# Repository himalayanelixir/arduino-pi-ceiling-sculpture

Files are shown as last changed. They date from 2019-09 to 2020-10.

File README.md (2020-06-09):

# Arduino Pi Ceiling Sculpture
<!-- vscode-markdown-toc -->
* [Summary](#Summary)
* [Setup](#Setup)
	* [Arduino](#Arduino)
	* [Raspberry Pi](#RaspberryPi)
* [Use](#Use)
	* [Format of the messages](#Formatofthemessages)
	* [Using the CVSs](#UsingtheCVSs)

<!-- vscode-markdown-toc-config
	numbering=false
	autoSave=true
	/vscode-markdown-toc-config -->
<!-- /vscode-markdown-toc -->

## Summary

Runs a ceiling sculpture using a Raspberry Pi as a master and multiple Arduinos as slaves. Thanks to the way the code is written, it's trivial to adapt code for any project that uses a text ui and cvs to send commands to as many Arduinos as you want!

Because the code is heavily commented, the focus of this README will be to get the code installed and then how to use the text ui to send commands to the Arduinos.

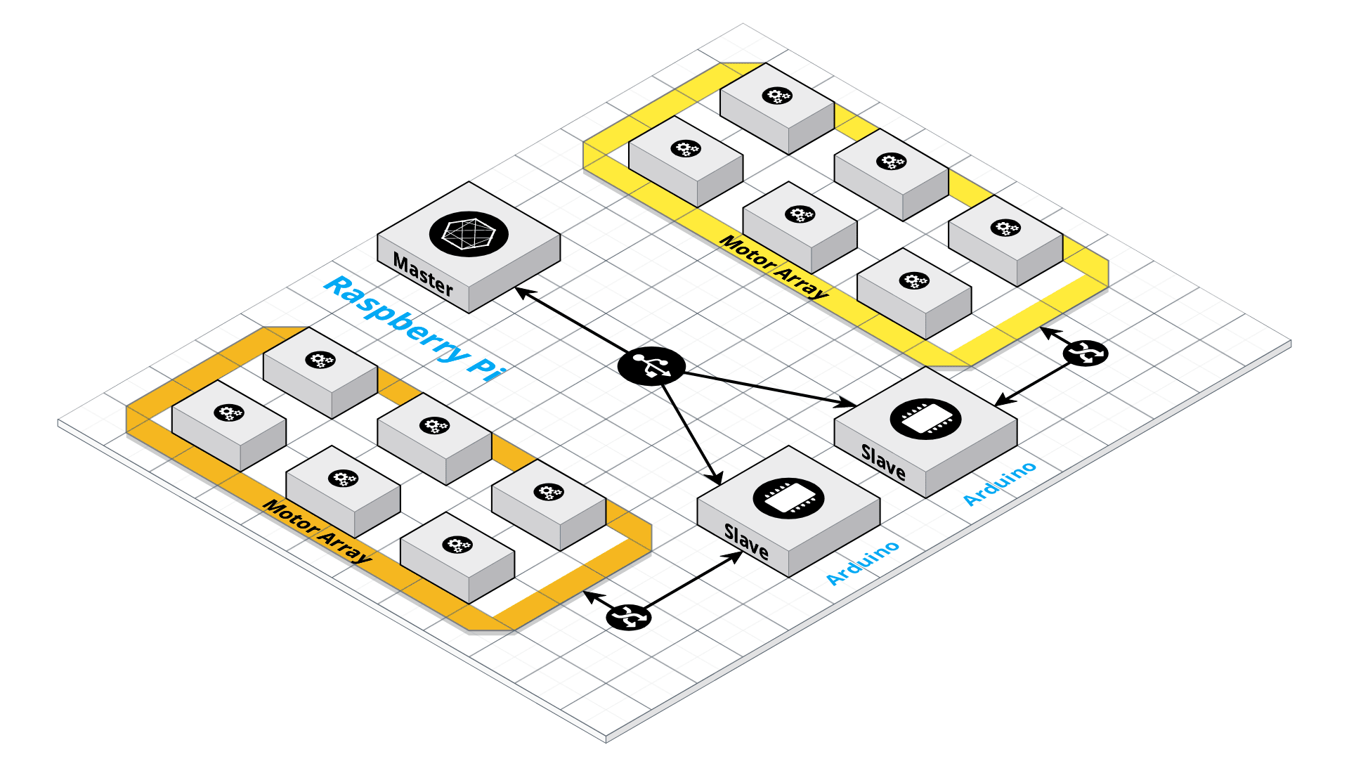
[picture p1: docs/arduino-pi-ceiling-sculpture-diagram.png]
Diagram

<p align="center"><i>Entire system</i></p>

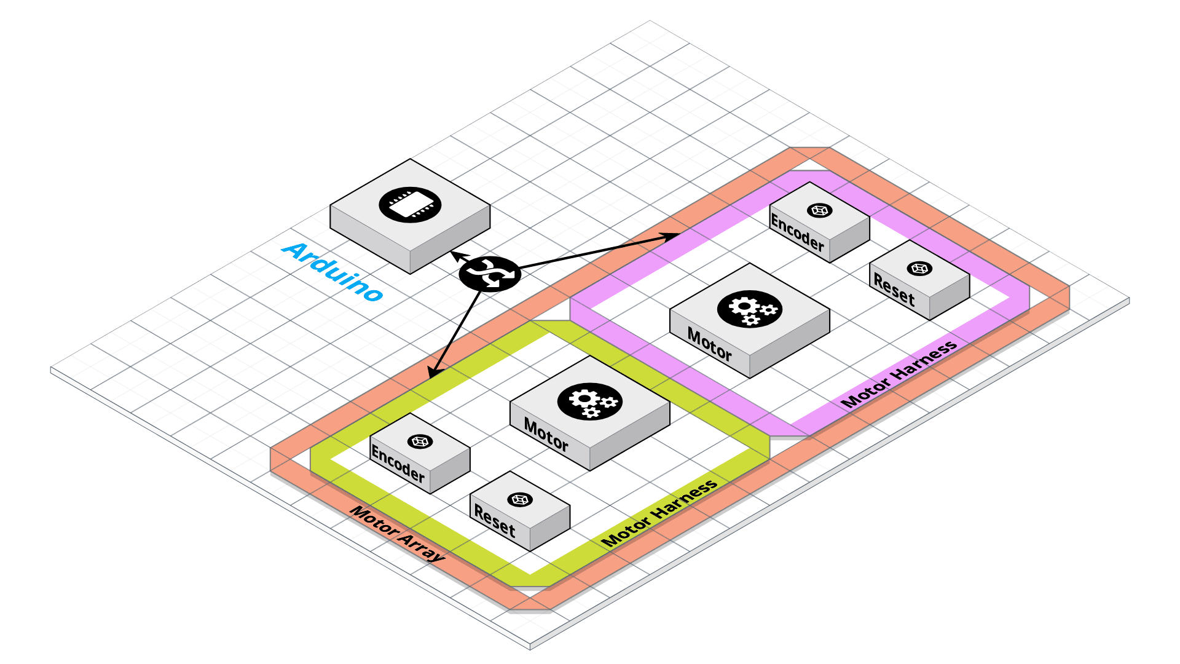
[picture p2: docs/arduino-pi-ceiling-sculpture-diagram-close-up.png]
Diagram

<p align="center"><i>Close up of an motor array</i></p>

## Setup

### Arduino

In the repo you will find the Arduino code under ```arduino/arduino.ino```. Open this in the Arduino IDE or CLI and flash to the devices you are using.

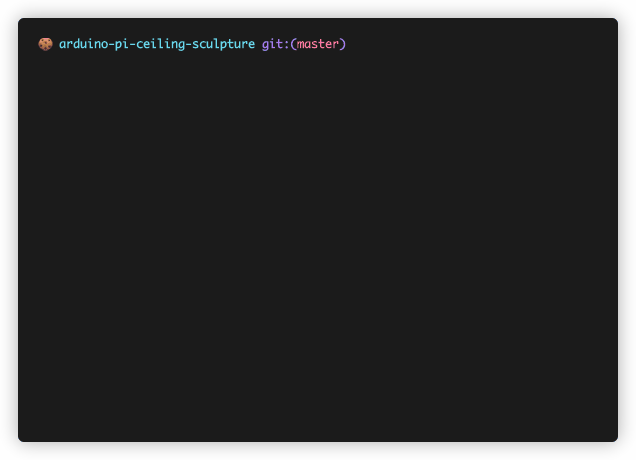
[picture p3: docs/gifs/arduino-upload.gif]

<p align="center"><i>Steps using the Arduino CLI</i></p>

There are only a few variables that can to be modified. Note that in this project and array refers to the combination of an Arduino and the motors that are connected to it. Each motor consists of a servo motor, and encoder switch, and a reset switch.

| Variable | Default | Description |
|---|---|---|
| DEBOUNCE_TIME | 0.4 | modifies the debounce time of the switches in the encoder. It is an arbitrary number and changed depending on the switches used for the encoder and reset |
| ARRAY_NUMBER | 0 | every array in the installation must have a unique array number that is between 0 and MAX_ARRAY_NUMBER (set on the Raspberry Pi) |
| NUMBER_OF_MOTORS | 1 | number of motors that you want to connect to this array |
| NUMBER_OF_MOTORS_MOVING | 1 | the execution of the commands is staggered/ cascaded from motor number 0 to NUMBER_OF_MOTORS. This is done to limit the amount of power being drawn at any one time|
| TIMEOUT | 50000 | this number counts the number of loops before the array returns a timeout error to the raspberry pi. The mount of time a loop takes is arbitrary and this number should be adjusted depending on what you need|
| IGNORE_INPUT_TIME | 150 | once the reset is hit we ignore inputs from the encoder switch for a certain number of loops. This is done so we skip an edge when moving down one turn from a reset event |
ports | {array}| array that contains the mapping of port number, function, and motor number

### Raspberry Pi

The Raspberry Pi setup is mostly automated using the script found at ```raspberry-pi/image-setup/firstboot.sh```. In the current setup I have an Raspberry connected to an Adafruit PiTFT Plus screen (<https://www.adafruit.com/product/2298>). If you aren't using the screen you can comment out those parts of the ```firstboot.sh``` script.  Also you can comment out the parts where it sets up the ```/raspberry-pi/gui.py``` file for the screen.

Note: The ```firstboot.sh``` pulls files from Github when running. The default is to pull from ```https://raw.githubusercontent.com/himalayanelixir/arduino-pi-ceiling-sculpture/master/``` change this if you want to pull from your own repo.

The best way to get everything working properly is to follow these steps:
1. Download the latest image from <https://github.com/nmcclain/raspberian-firstboot/releases>
2. Use etcher to write to the SD card (<https://www.balena.io/etcher/>)
3. Copy over ```raspberry-pi/image-setup/firstboot.sh``` and ```raspberry-pi/image-setup/wpa_supplicant.conf``` to boot partition of SD card. Remember to edit the `wpa_supplicant.conf` file with the details for your wifi network
4. Put the SD card into Raspberry Pi and boot. This will take a while but shouldn't take more than 30 mins. If it does, something probably went wrong.

It is important to note that ```firstboot.sh``` configures UFW (Uncomplicated Firewall) to block all outgoing and incoming network connections other than port 22 (SSH) from 192.168.1.0/24 (local network). This is done since we don't want the Raspberry Pi being accessed outside the local network or to pull updates which might break the applications. To connect to disable UFW run ```sudo ufw disable``` and enable using ```sudo ufw enable```.

There are a few variables that can be changed.

| Variable | Default | Description |
|---|---|---|
| MAX_TURNS | 10 | maximum number of turns a motor can take from 0 position used when linting csv files |
| MAX_NUMBER_OF_ARRAYS | 4 | maximum number of arrays allowed. Used then linting csv files |
| MAX_NUMBER_OF_MOTORS | 10 | maximum number of motors allowed. Used when linting csv file |
| USB_PATH | "/dev/ttyU*" | path the code looks for Arduinos at. All USB devices found will be considered to be Arduinos. |
| DESIRED_STATE_FILENAME | "desired-state.csv" | CSV file we are using to store our desired state for the ceiling |
| CURRENT_STATE_FILENAME | "current-state.csv" | CSV file we are using to store the current state of the ceiling |

## Use

Once the Arduinos are flashed and the Raspberry Pi is setup you plug the Arduinos into the Raspberry Pi. When you SSH into the Raspberry Pi using the pi user ```controller.pi``` will automatically run.

### Format of the messages

The messages between the Raspberry Pi and the Arduinos are formatted in strings. For example the string  ```<Up,1,Down,1>``` will tell the Arduino to move motor 0 up one turn and move motor 1 down 1 turn. You can even try this using the serial monitor in the Arduino IDE.

### Using the CVSs

```controller.py``` uses two CSVs to figure out what messages to send to the Arduinos. ```desired-state.csv``` contains a CVS which is used by the user to specify how many turns from 0 they want each motor to be at.

```current-state.csv``` contains the data on where each motor is currently. Both files are linted for size and contents before they are diffed and instructions are created. Any values that are out of the range of ```MAX_NUMBER_OF_MOTORS``` and ```MAX_NUMBER_OF_ARRAYS``` will be dropped. Any values that are blank, not integers, or don't exist will be filled with zeros. Values that are to large and too small will be replaced with ```MAX_TURNS``` or zero accordingly.

<p align="center"><img src="https://raw.githubusercontent.com/himalayanelixir/arduino-pi-ceiling-sculpture/master/docs/gifs/pi-controller.gif"></p>
<p align="center"><i>Running controller.py</i></p>

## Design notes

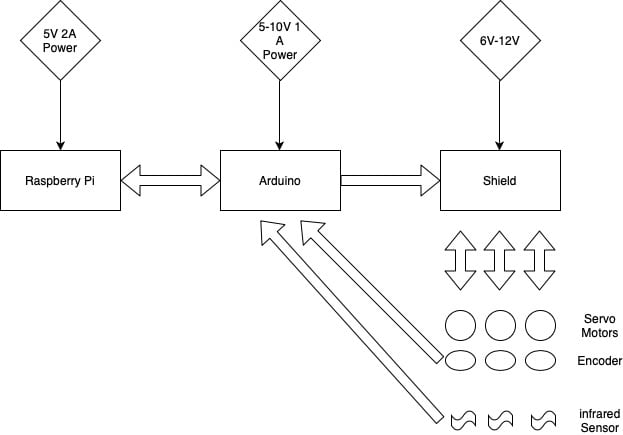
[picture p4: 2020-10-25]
parts/motor-harness/initial-design.jpg

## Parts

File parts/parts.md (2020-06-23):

<!-- vscode-markdown-toc -->
* [Parts](#Parts)

<!-- vscode-markdown-toc-config
	numbering=false
	autoSave=true
	/vscode-markdown-toc-config -->
<!-- /vscode-markdown-toc -->

## Parts

| Part | Part Name |
|---|---|
| Motors | FS5109R-V2 6V 10kg digital 360° Continuous Rotation Servo (FS5109R-C005) |
| 2 Pin Connectors  | KF301-2P |
| 3 Pin Connectors  | KF301-3P |
| 4 Pin Connectors  | KF301-4P |
| Male Headers | Male Header 0.1" 2.54mm Breadboard PCB Strip Connectors |
| Female Headers | Female Header 0.1" 2.54mm PCB Strip Connectors |
| Voltage Regulator | Pololu 9V Step-Up Voltage Regulator U3V12F9 |
| Arduino | Arduino Mega 2560 R3 |
| Raspberry Pi | Raspberry Pi 3 B+ |
| Power Wire | KabelDirekt - Pure Copper Stereo Audio Speaker - 16 AWG Gauge - 50 Feet  |
| Signal Wire | EWCS 22 AWG 3/C Str CMR Riser Rated Non-Shielded Sound & Security Cable  |
| PCBs | Oshpark |
| Switches | Cherry Red PCB Mount |
| Filament | SUNLU Wood Filament 2kg - 1.75 mm |
| Filament | Essentium PCTG |
| USB Cable | SNANSHI 25 Foot USB 2.0 Type A Male to Type B Male |
| Power Connectors  | WAGO 221-413 Lever-Nuts 3 Conductor Compact Connectors |
| Twine | Berkley Trilene Big Game Monofilament Custom Spool (30lbs) |
| Nozzle (Mounts) | Micro Swiss Plated Wear Resistant Nozzle .5mm |
| Nozzle (Tubes) | Micro Swiss Plated Wear Resistant Nozzle .8mm for Robo 3D |
| Hotend | RepRapDiscount Hexagon AO Hotend 1.75mm Kit |

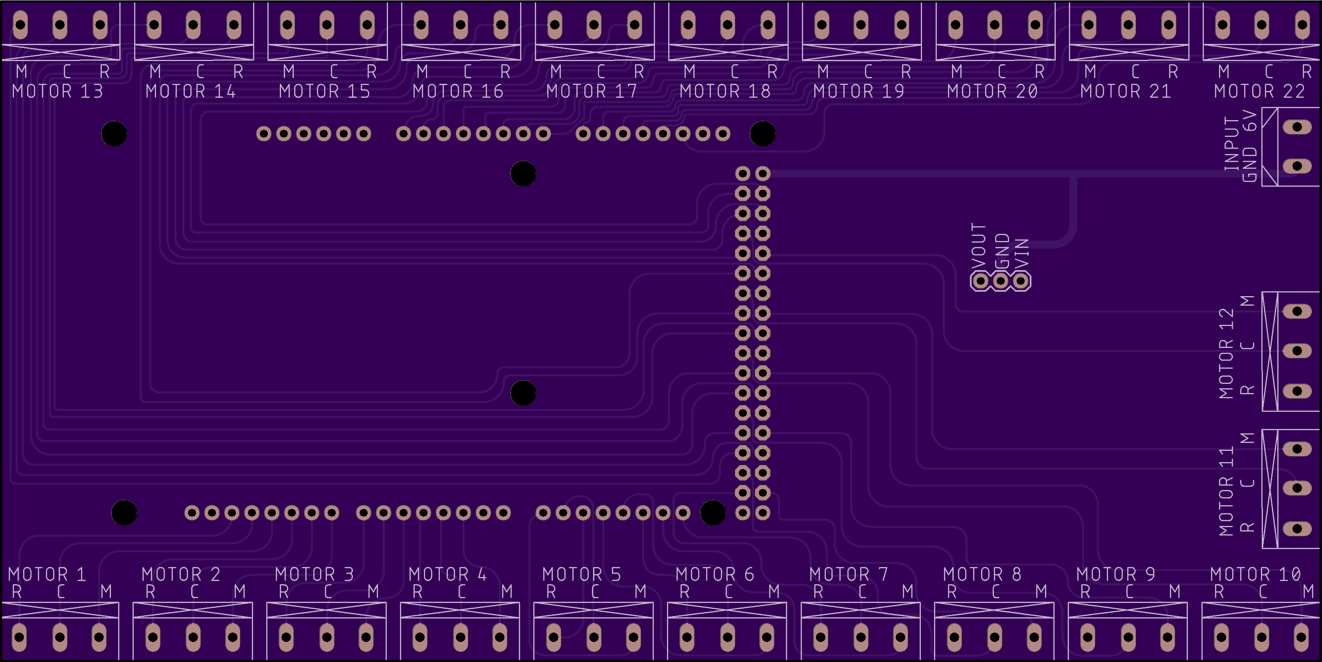
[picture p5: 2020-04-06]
parts/pcbs/arduino-top.png

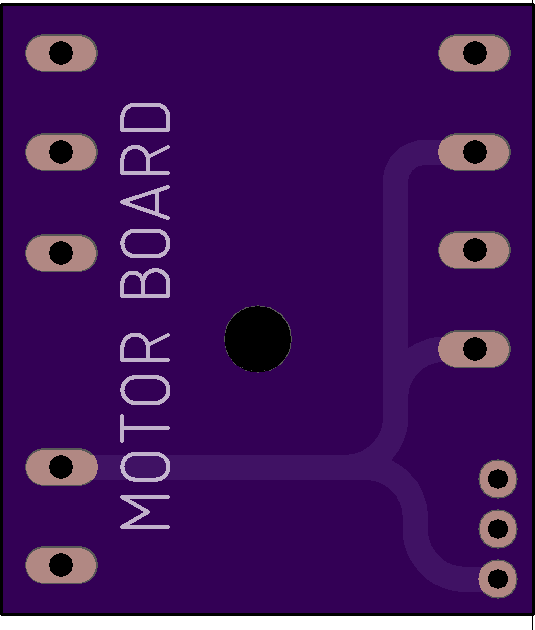
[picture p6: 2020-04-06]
parts/pcbs/motor-bottom.png

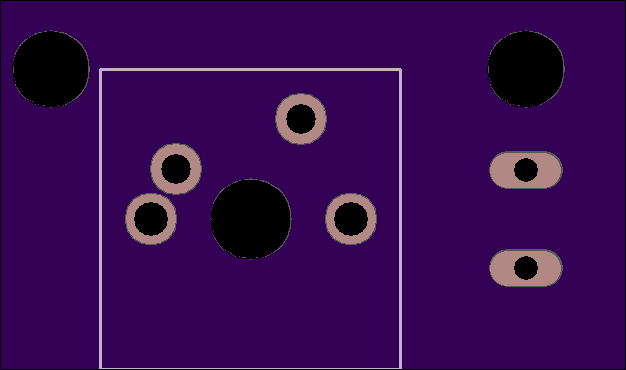
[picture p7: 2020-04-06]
parts/pcbs/switch-bottom.png

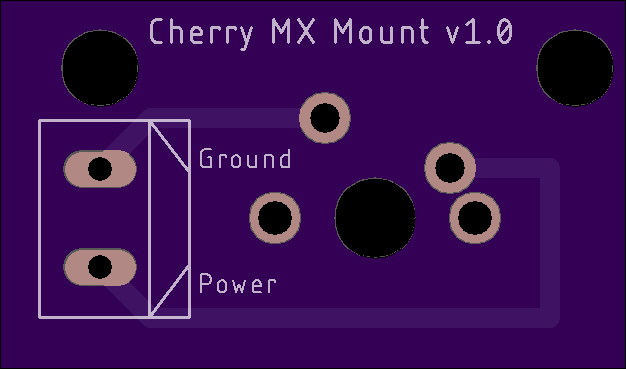
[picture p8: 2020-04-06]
parts/pcbs/switch-top.png

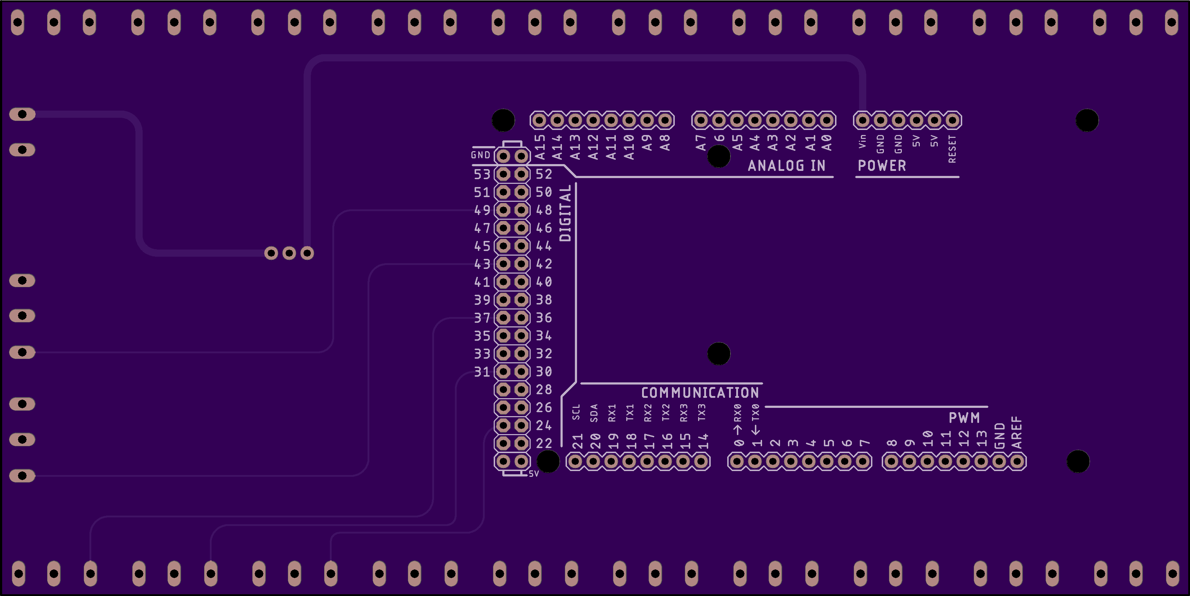
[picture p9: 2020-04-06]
parts/pcbs/arduino-bottom.png

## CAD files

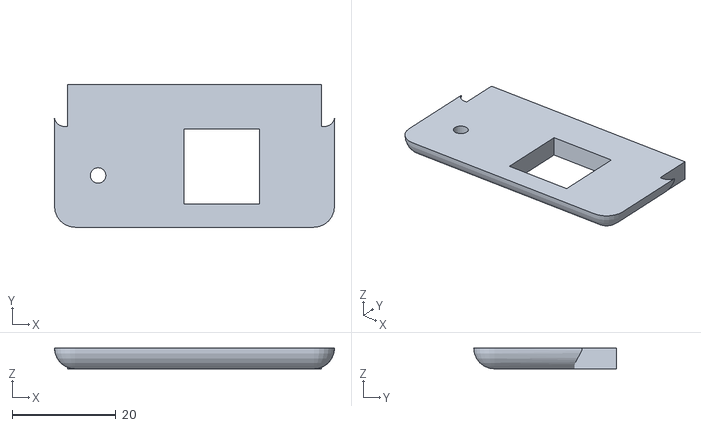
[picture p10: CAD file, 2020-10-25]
parts/motor-harness/mount5_part2.stl
54.0 x 27.5 x 4.00

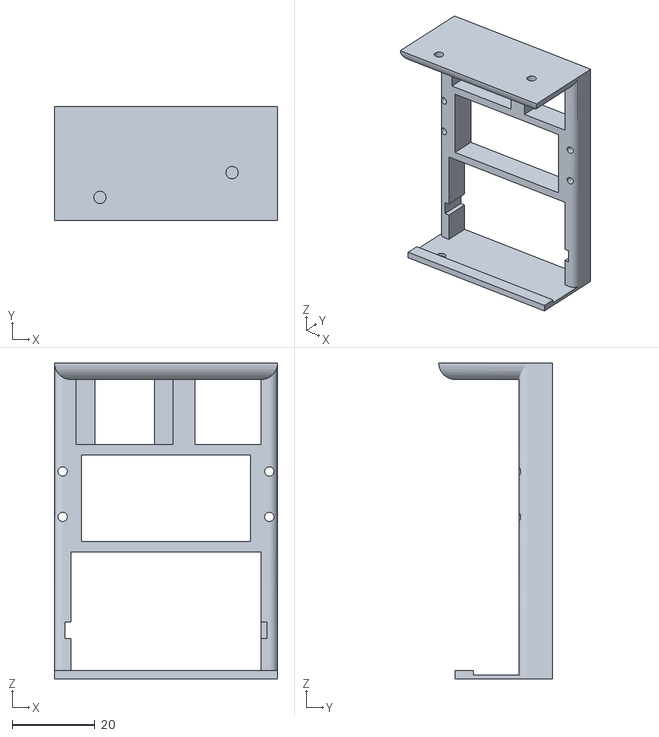
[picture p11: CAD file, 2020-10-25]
parts/motor-harness/mount5_part1.stl
54.0 x 27.5 x 76.5

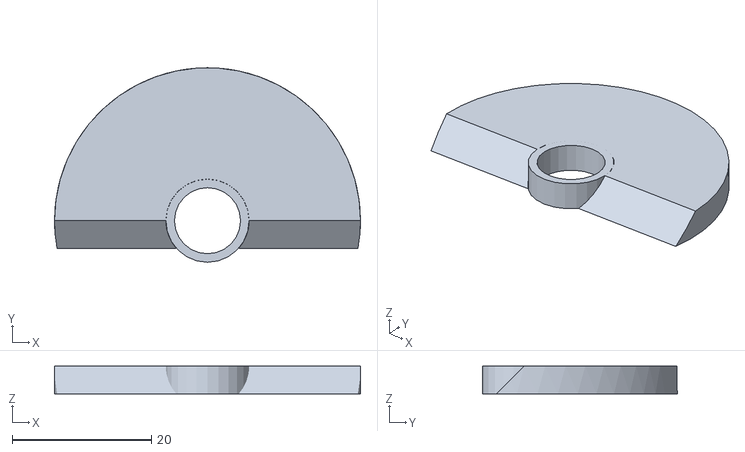
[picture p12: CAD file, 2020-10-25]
parts/motor-harness/spool5_part1.stl
44.0 x 28.0 x 4.00

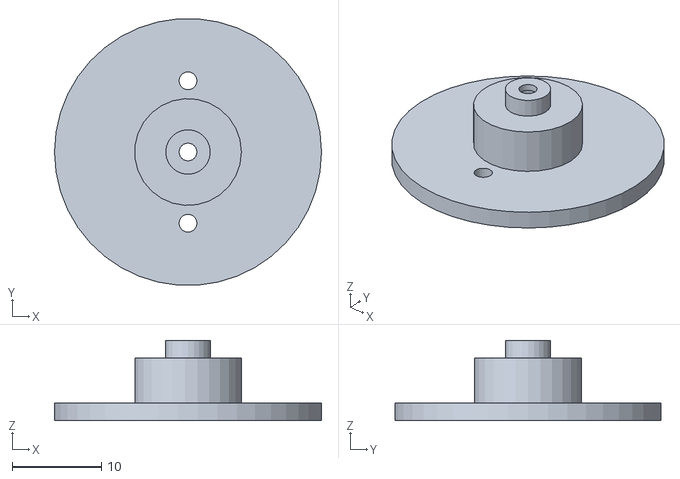
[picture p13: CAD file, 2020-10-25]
parts/motor-harness/spool5_part2.stl
30.0 x 29.9 x 9.00

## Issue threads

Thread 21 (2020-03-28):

Update README.md

himalayanelixir, 2020-03-28:
Provide instructions on how to get started with the code for both Arduino and Raspberry Pi

himalayanelixir, 2020-04-04:
1. Brief Overview
2. Setup Arduino
3. Setup Raspberry Pi
4. Functionality
pi -> arduino
input -> execution (error) -> result

Closed 2020-04-06.

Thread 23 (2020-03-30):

refactor controller.py to reduce complexity and make maintenance easier

himalayanelixir, 2020-03-30:
- currently the code is too nested and complex
- remove global variables if possible
- get pylint errors reduced
- add comments to the file

Closed 2020-03-31.

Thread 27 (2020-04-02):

fix pylint error

himalayanelixir, 2020-04-02:
raspberry-pi/controller.py:452:0: R0912: Too many branches (17/12) (too-many-branches)

Closed 2020-04-02.

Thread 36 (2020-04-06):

refactor broke arduino code - fix

himalayanelixir, 2020-04-06:
arduino doesn't accept commands anymore.

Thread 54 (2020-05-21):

motor timeout error not returning motor numbers

himalayanelixir, 2020-05-21:

himalayanelixir, 2020-05-21:
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

Closed 2020-05-23.

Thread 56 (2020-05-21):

motor out of range error isn't being caught

himalayanelixir, 2020-05-21:
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

himalayanelixir, 2020-05-21:
also display array number

himalayanelixir, 2020-05-21:
needs reformatting so error is raised only after all linting is complete on the array and motor numbers

Closed 2020-05-22.

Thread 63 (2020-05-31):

ufw setup bug

himalayanelixir, 2020-05-31:
ufw rules and enable aren't happening during firstboot all of a sudden - troubleshoot

himalayanelixir, 2020-05-31:
`# block all internet access other than incoming ssh from local network
# outgoing isn't blocked by default, we don't want updates unless we explicitly disable the firewall
ufw default deny outgoing
# allow local ssh
ufw allow from 192.168.0.0/16 to any port 22
# allow mDNS discovery on local network so 'ping raspberrypi.local' works
ufw allow out 5353/udp
# enable ufw, will auto start on boot
sudo ufw -f enable`

Closed 2020-06-04.

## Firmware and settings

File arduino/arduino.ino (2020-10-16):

// Copyright 2020 Harlen Bains
// Linted using cpplint
// Google C++ Style Guide https://google.github.io/styleguide/cppguide.html
#include <Servo.h>
#include <String.h>
// constants
// #define MAXIMUM_DEBOUNCE 8
#define MAXIMUM_DEBOUNCE 40
#define MAXIMUM_NUMBER_OF_MOTORS 22
#define ARRAY_NUMBER 0
#define NUMBER_OF_MOTORS 1
#define NUMBER_OF_MOTORS_MOVING 5
#define TIMEOUT 50000
#define MESSAGE_CHAR_LENGTH 300
// variables for communication
char received_chars[MESSAGE_CHAR_LENGTH];
bool new_data = false;
// create servo objects
Servo my_servo[NUMBER_OF_MOTORS];
// create a array of ports with the order: motor, counter, reset
int ports[MAXIMUM_NUMBER_OF_MOTORS][3] = {
    {11, 12, 13}, {8, 9, 10}, {5, 6, 7}, {2, 3, 4}, {14, 15, 16}, {17, 18, 19},
    {20, 21, 22}, {23, 24, 25}, {29, 30, 31}, {35, 36, 37}, {41, 42, 43},
    {47, 48, 49}, {26, 27, 28}, {32, 33, 34}, {38, 39, 40}, {44, 45, 46},
    {50, 51, 52}, {53, 54, 55}, {56, 57, 58}, {59, 60, 61}, {63, 64, 65},
    {62, 66, 67}
};
// integer array that contains the direction and number of rotations a motor,
// and a flag that determines if it's moving
int motor_commands[NUMBER_OF_MOTORS][3] = { 0 };
// array of new switch values
byte motor_sensor_counter1[NUMBER_OF_MOTORS] = { 0 };
// array of old switch values
byte motor_sensor_counter2[NUMBER_OF_MOTORS] = { 0 };
// Previous return value (CheckSwitch function)
int previous_value[NUMBER_OF_MOTORS] = { 1 };
// 0 or 1 depending on the input signal
byte input[NUMBER_OF_MOTORS] = { 0 };
// will range from 0 to the specified MAXIMUM_DEBOUNCE
int integrator[NUMBER_OF_MOTORS] = { 0 };
// cleaned-up version of the input signal
byte output[NUMBER_OF_MOTORS] = { 0 };
// other variables needed for the ProcessData() function
bool go = true;
int total_turns = 0;
int timeout_counter = 0;
int moving_motors = 0;
bool did_timeout = false;

void RecvWithStartEndMarkers() {
  // handles the receiving of data over the serial port
  static bool receive_in_progress = false;
  static int char_count = 0;
  char start_marker = '<';
  char end_marker = '>';
  char receive_from_usb;
  while (Serial.available() > 0 && new_data == false) {
    receive_from_usb = Serial.read();
    if (receive_in_progress == true) {
      if (receive_from_usb != end_marker) {
        received_chars[char_count] = receive_from_usb;
        char_count++;
        if (char_count >= MESSAGE_CHAR_LENGTH) {
          char_count = MESSAGE_CHAR_LENGTH - 1;
        }
      } else {
        received_chars[char_count] = '\0';  // terminate the string
        receive_in_progress = false;
        char_count = 0;
        new_data = true;
      }
    } else if (receive_from_usb == start_marker) {
      receive_in_progress = true;
    }
  }
}

void Finished() {
  // sends message back to raspberry pi saying the command has been executed
  if (did_timeout == true) {
    Serial.print("\033[31mRECIEVED: TIMEOUT - MOTOR(S): ");
    for (int i = 0; i < NUMBER_OF_MOTORS; i++) {
      if (motor_commands[i][1] != 0) {
        Serial.print(i);
        Serial.print(" ");
      }
    }
    Serial.print("\033[0m>");
  } else {
    Serial.print("\033[32mRECIEVED: SUCCESS\033[0m>");
  }
  for (int i = 0; i < NUMBER_OF_MOTORS; i++) {
    my_servo[i].write(90);
    motor_commands[i][0] = 0;
    motor_commands[i][1] = 0;
    motor_commands[i][2] = 0;
  }
}

void PopulateArray() {
  // fills array with instructions from the raspberry pi
  // temp string used to store the char array
  // easier to do opperations on string than chars
  String received_string = "";
  // give the string the value of the char array
  received_string = received_chars;
  // now lets populate the motor command array with values from the received
  // string
  for (int i = 0; i < NUMBER_OF_MOTORS; i++) {
    // we break everything in to pairs of values
    int search_1 = (i *2);
    int search_2 = ((i *2) + 1);

    String value_1 = GetValue(received_string, ',', search_1);
    String value_2 = GetValue(received_string, ',', search_2);

    if (value_1 == "Up") {
      motor_commands[i][0] = 1;
      // need to add one to up commands to deal with integrator and counter
      // values, forcing an edge
      motor_commands[i][1] = value_2.toInt() + 1;
      integrator[i] = 0;
      motor_sensor_counter1[i] = 0;
      motor_sensor_counter2[i] = 0;
    } else if (value_1 == "Down") {
      motor_commands[i][0] = 2;
      motor_commands[i][1] = value_2.toInt() + 1;;
      integrator[i] = MAXIMUM_DEBOUNCE;
      motor_sensor_counter1[i] = 1;
      motor_sensor_counter2[i] = 1;
    } else {
      motor_commands[i][0] = 0;
      motor_commands[i][1] = 0;
    }
  }
}

String GetValue(String data, char separator, int index) {
  // helps get a particular value from the incoming data string
  int found = 0;
  int string_index[] = { 0, -1 };
  int maximum_index = data.length() - 1;

  for (int i = 0; i <= maximum_index && found <= index; i++) {
    if (data.charAt(i) == separator || i == maximum_index) {
      found++;
      string_index[0] = string_index[1] + 1;
      string_index[1] = (i == maximum_index) ? i + 1 : i;
    }
  }
  return found > index ? data.substring(string_index[0], string_index[1]) : "";
}

void ProcessData() {
  // function that moves the motors and executes till they are done moving or
  // timeout
  while (go == true) {
    // initialize motors and get them moving
    for (int i = 0; i < NUMBER_OF_MOTORS; i++) {
      CountMoving();
      if (moving_motors < NUMBER_OF_MOTORS_MOVING &&
        motor_commands[i][2] != 1) {
        if (motor_commands[i][1] != 0) {
          StartMotors(i);
          motor_commands[i][2] = 1;
        }
      }
    }

    // subtract from motor rotations when a rotation is detected
    for (int i = 0; i < NUMBER_OF_MOTORS; i++) {
      if (motor_commands[i][2] == 1) {
        CheckCounter(i);
        // stop motors that have reached 0
        if (motor_commands[i][1] <= 0) {
          my_servo[i].write(90);
          motor_commands[i][2] = 0;
        }
      }

      // stop motors that have hit the reset
      // first stop the motor and then tell the code to move it down one
      // rotation
      if (digitalRead(ports[i][2]) == 0) {
        my_servo[i].write(110);
        motor_commands[i][0] = 2;
        motor_commands[i][1] = 1;
        motor_commands[i][2] = 0;
      }
    }
    // see how many turns are left in the array
    // we want to zero it every time we recalculate the number of turns
    total_turns = 0;
    for (int i = 0; i < NUMBER_OF_MOTORS; i++) {
      total_turns += motor_commands[i][1];
    }
    // exit loop if there are no more motor rotations remaining
    if (total_turns <= 0) {
      go = false;
    }
    timeout_counter = timeout_counter + 1;
    // time out loop if stall
    if (timeout_counter >= TIMEOUT) {
      go = false;
      did_timeout = true;
      for (int i = 0; i < NUMBER_OF_MOTORS; i++) {
        my_servo[i].write(90);
      }
    }
  }
}

int CountMoving() {
  // count the number of moving motors
  moving_motors = 0;
  for (int i = 0; i < NUMBER_OF_MOTORS; i++) {
    moving_motors += motor_commands[i][2];
  }
}

void CheckCounter(int i) {
  // check to see if we are on a rising edge
  motor_sensor_counter2[i] = motor_sensor_counter1[i];
  motor_sensor_counter1[i] = CheckSwitch(i, ports[i][1]);
  if (motor_commands[i][0] == 1) {
    // if up
    if (motor_sensor_counter1[i] == 1 && motor_sensor_counter2[i] == 0) {
      motor_commands[i][1] = motor_commands[i][1] - 1;
    }
  } else {
    // if down
    if (motor_sensor_counter1[i] == 0 && motor_sensor_counter2[i] == 1) {
      motor_commands[i][1] = motor_commands[i][1] - 1;
    }
  }
  if (motor_commands[i][1] < 0) {
    motor_commands[i][1] = 0;
  }
}

int CheckSwitch(int motor_number, int switchPort) {
  // check to see if the encoder switch is pressed or not
  /*Step 1: Update the integrator based on the input signal.  Note that the
  integrator follows the input, decreasing or increasing towards the limits
  as determined by the input state (0 or 1). */
  input[motor_number] = digitalRead(switchPort);

  if (input[motor_number] == 0) {
    if (integrator[motor_number] > 0)
      integrator[motor_number]--;
  } else {
    if (integrator[motor_number] < MAXIMUM_DEBOUNCE)
      integrator[motor_number]++;
  }
  /*Step 2: Update the output state based on the integrator.  Note that the
  output will only change states if the integrator has reached a limit,
  either 0 or MAXIMUM_DEBOUNCE. */
  if (integrator[motor_number] <= 0) {
    previous_value[motor_number] = 0;
    return (0);
  } else if (integrator[motor_number] >= MAXIMUM_DEBOUNCE) {
    previous_value[motor_number] = 1;
    return (1);
  } else {
    return (previous_value[motor_number]);
  }
}

void StartMotors(int i) {
  // move motors
  if (motor_commands[i][0] == 1) {
    // Move up
    my_servo[i].write(80);
  } else if (motor_commands[i][0] == 2) {
    // Move down
    my_servo[i].write(110);
  } else {
    // Don't Move
    my_servo[i].write(90);
  }
}

void setup() {
  // setup serial port
  Serial.begin(9600);
  for (int i = 0; i < NUMBER_OF_MOTORS; i++) {
    // initialize all motor ports
    int x = ports[i][0];
    my_servo[i].attach(x);
    // initialize all counter ports
    int y = ports[i][1];
    pinMode(y, INPUT_PULLUP);
    // initialize all reset ports
    int z = ports[i][2];
    pinMode(z, INPUT_PULLUP);
    // zero all motors and initialize reset variables
    my_servo[i].write(90);
    motor_sensor_counter1[i] = 1;
    motor_sensor_counter2[i] = 1;
    output[i] = 1;
  }
  Serial.print("<Arduino is Ready Array Number: ");
  Serial.print(ARRAY_NUMBER);
  Serial.print(" Number of Motors: ");
  Serial.print(NUMBER_OF_MOTORS);
  Serial.print(">");
}

void loop() {
  // check to see if there is any new data
  RecvWithStartEndMarkers();
  // if there is new data process it
  if (new_data == true) {
    new_data = false;
    go = true;
    did_timeout = false;
    timeout_counter = 0;
    Serial.print("<");
    PopulateArray();
    ProcessData();
    Finished();
  }
}

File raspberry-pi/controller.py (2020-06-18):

#!/home/pi/code/pi_env/bin/python3
# Copyright 2020 Harlen Bains
# linted using pylint
# formatted using black
# pylint: disable=duplicate-code
"""This script runs on the Raspberry Pi and sends commands to Arduinos.
Once a command is sent it then waits a reply and then loops.
"""

import csv
import shutil
import subprocess
import time
import glob
import os
from threading import Thread
import serial  # pylint: disable=import-error
from yaspin import yaspin  # pylint: disable=import-error
from yaspin.spinners import Spinners  # pylint: disable=import-error
import timeout_decorator  # pylint: disable=import-error
import questionary  # pylint: disable=import-error


# constants
# don't change
BAUD_RATE = 9600
START_MARKER = 60
END_MARKER = 62
SPINNER = yaspin(Spinners.weather)
ARDUINO_MESSAGE_TIMEOUT = 10
ARDUINO_EXECUTE_TIMEOUT = 100
# adjustable
# positive integers only
MAX_TURNS = 20
MAX_NUMBER_OF_ARRAYS = 36
MAX_NUMBER_OF_MOTORS = 22
# USB_PATH = "/dev/ttyU*"
USB_PATH = "/dev/ttyACM*"
CSV_PATH = "/home/pi/"
CURRENT_STATE_FILENAME = "code/current-state.csv"


class Error(Exception):
    """Exception that is raised when an error occurs in the program
    causes the program to print out a message and then loop.
    """


def find_arduinos():
    """Run ls command and find all USB devices connected to USB hub
     assume that all of them are Arduinos.

    Returns:
      A list of all the ports that are active on the USB hub.

    Raises:
      Error: if no arrays are found or if more than MAX_NUMBER_OF_ARRAYS is
    found.
    """
    # run ls in subprocess shell and save results
    try:
        path_command = "ls " + USB_PATH
        serial_shell_capture = subprocess.run(
            [path_command], shell=True, capture_output=True, check=True
        )
        # take results and convert byte string into utf-8 and create list based on newlines
        serial_shell_capture_list = serial_shell_capture.stdout.decode(
            "utf-8"
        ).splitlines()
        # if there is at least one array found then print out number found
        # other wise print zero and error
        print(
            f"Found \033[32m{len(serial_shell_capture_list)}\033[0m Array(s)",
            f"of Max of {MAX_NUMBER_OF_ARRAYS}",
        )
        # make sure that the # arrays found is less than or equal to MAX_NUMBER_OF_ARRAYS
        if len(serial_shell_capture_list) > MAX_NUMBER_OF_ARRAYS:
            # make list empty so we don't try to close ports when this error occurs
            serial_shell_capture_list = []
            print(
                f"\033[31mERROR: NUMBER OF ARRAYS FOUND GREATER THAN {MAX_NUMBER_OF_ARRAYS}\033[0m"
            )
            raise Error
    except subprocess.CalledProcessError:
        # need to still have a valie
        serial_shell_capture_list = []
        print(f"\nFound \033[31m0\033[0m Array(s) of Max {MAX_NUMBER_OF_ARRAYS}")
        print(f"\033[31mERROR: NO ARRAYS FOUND\033[0m")
        raise Error
    return serial_shell_capture_list


def lint_csv_file(csv_filename):
    """Lint file table is the corret size and values are valid.

    Args:
      csv_filename: The name of the file we are linting.

    Raises:
      Error: If the program can not read the file.
      Error: If the program can not write to the file.
    """
    csv_filename_list = []
    # we initialize this list to a particular size becuase we then iterate over it and
    # copy values from csv_filename_list. When copying we also make sure that the
    # values are allowed (filters out non ints and values that are too high or low)
    csv_filename_list_linted = [
        ["0" for x in range(MAX_NUMBER_OF_MOTORS)] for y in range(MAX_NUMBER_OF_ARRAYS)
    ]
    try:
        with open(csv_filename, "r") as csv_filename_file:
            csv_filename_reader = csv.reader(csv_filename_file, delimiter=",")
            csv_filename_list = list(csv_filename_reader)
            for count_row in range(0, MAX_NUMBER_OF_ARRAYS):
                for count_column in range(0, MAX_NUMBER_OF_MOTORS):
                    try:
                        # pylint: disable=C0330
                        if (
                            int(csv_filename_list[count_row][count_column]) <= MAX_TURNS
                            and int(csv_filename_list[count_row][count_column]) > 0
                            and csv_filename_list[count_row][count_column] != ""
                            and isinstance(
                                int(csv_filename_list[count_row][count_column]), int
                            )
                        ):
                            csv_filename_list_linted[count_row][
                                count_column
                            ] = csv_filename_list[count_row][count_column]
                        else:
                            csv_filename_list_linted[count_row][count_column] = "0"
                    except (IndexError, ValueError):
                        csv_filename_list_linted[count_row][count_column] = "0"
    except EnvironmentError:
        SPINNER.write(
            csv_filename + " (\033[31m" + "ERROR: CAN'T READ CSV" + "\033[0m)"
        )
        raise Error
    # write values to file overwriting previous file
    try:
        with open(csv_filename, "w", newline="") as csv_filename_file:
            csv_filename_writer = csv.writer(csv_filename_file, quoting=csv.QUOTE_ALL)
            csv_filename_writer.writerows(csv_filename_list_linted)
            SPINNER.write(csv_filename + " (\033[32m" + "COMPLETE" + "\033[0m)")
    except EnvironmentError:
        SPINNER.write(
            csv_filename + " (\033[31m" + "ERROR: CAN'T WRITE CSV" + "\033[0m)"
        )
        raise Error
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

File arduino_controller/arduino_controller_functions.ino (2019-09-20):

//////////////////////////////////////////////////////////////////////////////
//////////////////////////////////////////////////////////////////////////////

// This file contains functions that process the data that is received from the
// raspberry pi

//////////////////////////////////////////////////////////////////////////////
//////////////////////////////////////////////////////////////////////////////

void ProcessData()
{
  // Added this because reset code is different from regular movement code
  bool is_reset = false;
  bool go = true;
  int total_turns = 0;
  long timeout_counter = 0;

  PopulateArray();

  // initialize all motors and get them moving
  for (int i = 0; i < NUMBER_MOTORS; i++)
  {
    if (motor_commands[i][0] == 0)
    {
      my_servo[i].write(100);
      Serial.println("Reached Up");
      is_reset = false;
    }
    else if (motor_commands[i][0] == 1)
    {
      my_servo[i].write(80);
      Serial.println("Reached Down");
      is_reset = false;
    }
    else if (motor_commands[i][0] == 2)
    {
      my_servo[i].write(90);
      Serial.println("Reached Stopped");
      is_reset = false;
    }
    else if (motor_commands[i][0] == 3)
    {
      // Start moving pieces up
      my_servo[i].write(100);
      Serial.println("Reached Reset");
      is_reset = true;
      // call reset function (still needs to be written)
    }
    else
    {
      // Sends Error Message
    }
  }

  if (is_reset == false)
  {
    while (go == true)
    {
      // subtract from motor rotations when a rotation is detected
      for (int i = 0; i < NUMBER_MOTORS; i++)
      {
        motor_sensor_counter2[i] = motor_sensor_counter1[i];
        motor_sensor_counter1[i] = CheckSwitch(i, ports[i][1]);

        if (motor_sensor_counter1[i] == 1 && motor_sensor_counter2[i] == 0)
        {
          motor_commands[i][1] = motor_commands[i][1] - 1;
        }

        if (motor_commands[i][1] < 0)
        {
          motor_commands[i][1] = 0;
        }
      }
      // stop motors that have reached 0
      for (int i = 0; i < NUMBER_MOTORS; i++)
      {
        if (motor_commands[i][1] <= 0)
        {
          my_servo[i].write(90);
        }
      }
      // see how many turns are left in the array
      for (int i = 0; i < NUMBER_MOTORS; i++)
      {
        total_turns += motor_commands[i][1];
        // Serial.print("Total number of turns in array: ");
        // Serial.println(total_turns);
      }
      // print the total number of turns left for each motor
      for (int i = 0; i < NUMBER_MOTORS; i++)
      {
        Serial.print("Motor ");
        Serial.print(i);
        Serial.print(": ");
        Serial.print(motor_commands[i][1]);
        Serial.print(" --  ");
      }
      Serial.println("");

      // exit loop if there are no more motor rotations remaining
      if (total_turns <= 0)
      {
        go = false;
      }
      total_turns = 0;

      // time out loop if stall
      if (timeout_counter >= TIMEOUT)
      {
        go = false;
        for (int i = 0; i < NUMBER_MOTORS; i++)
        {
          my_servo[i].write(90);
          Serial.println("Timeout");
        }
      }
      timeout_counter = timeout_counter + 1;
      Serial.println(timeout_counter);
    }
  }
  else
  {
    int reset_counter[NUMBER_MOTORS] = {0};

    for (int i = 0; i < NUMBER_MOTORS; ++i){
      reset_counter[i] = 1;
    }

    while (go == true)
    {
      // stop motors that have reached 0
      for (int i = 0; i < NUMBER_MOTORS; i++)
      {
        if (digitalRead(ports[i][2]) == 0)
        {
          my_servo[i].write(90);
          reset_counter[i] = 0;
        }
      }
      // see how many turns are left in the array
      for (int i = 0; i < NUMBER_MOTORS; i++)
      {
        total_turns += reset_counter[i];
      }

      Serial.print("Total Turns: ");
      Serial.println(total_turns);

      if (total_turns <= 0)
      {
        go = false;
      }
      total_turns = 0;

      if (timeout_counter >= TIMEOUT)
      {
        go = false;
        for (int i = 0; i < NUMBER_MOTORS; i++)
        {
          my_servo[i].write(90);
          Serial.println("Timeout");
        }
      }
      timeout_counter = timeout_counter + 1;
      Serial.println(timeout_counter);
    }
  }
  // Send Finished Signal
  Finished();
}

//////////////////////////////////////////////////////////////////////////////
//////////////////////////////////////////////////////////////////////////////

void PopulateArray()
{

  // temp string used to store the char array
  // easier to do opperations on string than chars
  String received_string = "";
  // give the string the value of the char array
  received_string = received_chars;

  // now lets populate the motor command array with values from the received
  // string
  for (int i = 0; i < NUMBER_MOTORS; i++)
  {
    int search1 = (i * 2);
    int search2 = ((i * 2) + 1);

    String value1 = getValue(received_string, ',', search1);
    String value2 = getValue(received_string, ',', search2);

    if (value1 == "Up")
    {
      motor_commands[i][0] = 0;
    }
    else if (value1 == "Down")
    {
      motor_commands[i][0] = 1;
    }
    else if (value1 == "None")
    {
      motor_commands[i][0] = 2;
    }
    else if (value1 == "Reset")
    {
      motor_commands[i][0] = 3;
    }
    else
    {
      // Sends Error Message
      Invalid();
    }

    motor_commands[i][1] = value2.toInt();
  }

  // print array
  for (int i = 0; i < NUMBER_MOTORS; i++)
  {
    Serial.print("Motor Number: ");
    Serial.print(i);
    Serial.print(" - Direction: ");
    Serial.print(motor_commands[i][0]);
    Serial.print(" - Rotations: ");
    Serial.println(motor_commands[i][1]);
  }
}

//////////////////////////////////////////////////////////////////////////////
//////////////////////////////////////////////////////////////////////////////

int CheckSwitch(int motor_number, int switchPort)
{
  /* Step 1: Update the integrator based on the input signal.  Note that the
    integrator follows the input, decreasing or increasing towards the limits
    as determined by the input state (0 or 1). */
  input[motor_number] = digitalRead(switchPort);

  if (input[motor_number] == 0)
  {
    if (integrator[motor_number] > 0)
      integrator[motor_number]--;
  }
  else if (integrator[motor_number] < MAXIMUM)
    integrator[motor_number]++;

  /* Step 2: Update the output state based on the integrator.  Note that the
    output will only change states if the integrator has reached a limit,
    either 0 or MAXIMUM. */

  if (integrator[motor_number] == 0)
    return (0);
  else if (integrator[motor_number] >= MAXIMUM)
  {
    return (1);
    integrator[motor_number] = MAXIMUM; /* defensive code if integrator got corrupted */
  }
}

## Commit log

2018-04-04 Added Python File for Pi
    Currenty sends commands to and receves replies from Arduino
2018-04-04 Added working version of code on Arduino
2018-06-06 Working communication between arduino and python program
    Working communication between arduino and python program
2018-06-06 Moved motor movent into funtions
2018-06-06 Refactoring to handle more than 1 motor
2018-06-11 Added IR Sensor Read File
2018-06-18 Added 3D Printer Models
    [Servo_Winch_Bearing_Pin.stl, Servo_Winch_Bulkhead_Chassis.STL, Servo_Winch_Chassis.STL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]
2018-07-10 Updated 3D printer models and added demo code
    [Servo_Winch_Bearing_Pin.stl, Servo_Winch_Bulkhead_Chassis.STL, Servo_Winch_Chassis.STL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]
2018-08-11 Updated 3D Printer Models
    [Motor Mount v14.stl, Spool v10.stl, Spool v12.stl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]
2019-03-30 Updated Processing Function and Fixed Bug in ProcessingArray Function
    [arduino_controller_functions.ino]
2019-04-03 Finished adding basic dynamic motor control code
    Doesn't include reset functionality
    [arduino_controller_functions.ino]
2019-04-03 Fixed small compile errors and formatting
    [arduino_controller_functions.ino]
2019-04-20 Added 9 motor mappings and test strings
2019-07-29 Added relay functionality
2019-09-03 new models
    [Mount_190807.stl, Reel_190724.stl, Switchstop_190726.stl]
2019-09-03 Added stall detection code
    [arduino_controller_functions.ino]
2019-09-04 Stop all motor movement when timing out
2019-09-04 Fixed formatting and reset and timeout are working
    [arduino_controller_functions.ino]
2019-09-20 Fixed reset bug and added new port mappings
    [arduino_controller_functions.ino]
2019-09-24 Updating Pi Code to handle multiple Arduinos
    - Still need to implement listening. Right now the code just opens and closes the ports needed to communicate with the boards.
2019-09-24 Got Multiboard Control Working!
    Working multiboard control
    issues:
    - Code needs to be cleaned up
    - needs to be formatted
    [contoller.py]
2019-09-26 Cleaned Repo & Added Better Printouts to Pi Code
    [Motor Mount v14.stl, Mount_190807.stl, Reel_190724.stl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]
2019-09-26 Formatting Arduino Code
2019-12-04 Removed relay control code
    Remove relay code since we aren't using the relay on the mega board anymore.
2019-12-06 Added motor cascading and reimplemented reset logic with move down functionality
2019-12-12 Updated motor numbers and fixed a bug in the code
2019-12-20 Updated arduino test folder
2020-02-06 Create Arduino_Ceiling_Sculpture_Platform.png
2020-02-06 Create Arduino_Ceiling_Sculpture_Platform-2.png
2020-03-16 Fixing raspberry pi config files
2020-03-19 Updated Image Commands and Removed Invalid Function from Arduino Code
2020-03-19 Updated Arduino Code
    - Added better error reporting
2020-03-19 Fixed Arduino Code Formatting
    - Used http://format.krzaq.cc to format code
2020-03-20 Replaced setup.sh with firstboot.sh
    - automates the instalation of everything needed to run controller.py and also ohmyzsh and Adafruit screen drivers
    - TODO: copy controller.py from github onto pi during setup
2020-03-22 Changed program flow of controller.py
2020-03-22 fixing errors in controller.py and adding testing files
    [controller.py]
2020-03-23 Issue #10 fix virtualenv issue (#11)
    * Fixed the use of virtualenvs and updted firstboot script
    * Updating firstboot.sh with new urls
    * Reverted download changes
    [controller.py]
2020-03-24 Issue #6 controller.py doesn't use csvs (#12)
    * added extra options for csv execution
    * moved files around
    * finished linting function
    * removed extra import
    * controller.py got getCommands() working
    * added reset and exeute functions to controller.py
    [current_state.csv, desired_state.csv]
2020-03-24 moved csvs
    [current_state.csv, desired_state.csv]
2020-03-27 Issue #16 combine functions (#17)
    * Combined functions
    * Fixed extra quotes
    [controller.py]
2020-03-28 Issue #16 run pylint (#18)
    * ran pylint.py and ran black on all py files
    [controller.py]
2020-03-30 Issue #7 auto detect arduinos and lint csvs (#22)
    * serial port addresses are now dynamic
    * code now prints out number of arduinos connected to usb hub
    * array number and number of motors now stored in SERIAL_PORT list
    * fixing printouts
    * Added linting of csv size
    * added linting of serial_port values
    * updated csv_commands() to be dynamic
    [controller.py]
2020-03-31 Issue #23 refactor controller file (#24)
    * refactored first loop of program
    * removed serial_objects variable and ran pylint
    * added comments
    * added printouts and error checking to linting functions
    * made csv filenames into variables
    * refactored csv functions to reduce duplicated code
    * updated naming of functions and variables
    * ran black formatter
    [controller.py]
2020-03-31 updated folder and filenames
    [current-state.csv, desired-state.csv]
2020-04-02 Issue #25 - test code and make changes
    - added more error checking
    - fixed small bugs
    - also updated tui printouts
    [controller.py]
2020-04-02 Issue #21 changed program flow so csvs are in the 2nd loop
    [controller.py]
2020-04-02 Issue #27 fix error handling (#28)
    * replaced all error variables with exeptions
    * fixing pylint errors
    - got code to 10/10
    [controller.py]
2020-04-04 combined arduino code into one file and formatted
2020-04-05 added complete port mapping to arduino.ino file and fixed variable name formats (#33)
    [arduino.ino]
2020-04-06 Issue #21 update README.md (#34)
    * Created arduino-pi-ceiling-sculpture-diagram-closeup.png
    * Fixing spelling
    * Updated README
    [arduino.ino, controller.py]
2020-04-06 Fixed the issue (#38)
    [arduino.ino, test.ino]
2020-04-06 added PCBs to repo
    [arduino-mega-board.brd, cherry-switch-board.brd, motor-board.brd]
2020-04-07 added controller.py gif #35
    [pi-controller.yml]
2020-04-07 fixed issue where csv's were being checked on exit
    [controller.py]
2020-04-09 updated pi-controller.gif
    [pi-controller.yml]
2020-04-16 renamed resources/ folder to docs/ folder
    [pi-controller.yml]
2020-05-01 updated pcb names
    [arduino.brd, switch.brd]
2020-05-06 removed adafruit driver install from firstboot.sh
2020-05-06 updated gui.py to use gpio leds instead of lcd screen
    - fix led colors
    - fix delays with ping
2020-05-06 close #46 updated led colors
2020-05-07 updated firewal led pins
2020-05-07 closed #48 added button functionality
2020-05-08 renamed gui.py to leds.py
    we don't use a screen anymore and have leds instead
2020-05-09 fixed errors in shutdown and restart sequences
    [button.py]
2020-05-09 updated LED colors
2020-05-12 close #49 removed redundant reset command
    [arduino.ino]
2020-05-12 cleaning up arduino code
2020-05-20 close #52
    ufw firewall now allows mDNS, this way 'ping raspberrypi.local' works
2020-05-22 closed #56 #55 fixed array number and motor number error messages
    [controller.py]
2020-05-23 closed #54
    there was no error, was using the program incorrectly
    [controller.py, test.ino]
2020-05-23 changed success print out to complete print out
2020-05-23 moving current-state.csv to code directory
2020-05-23 updated arduino.ino print statements
2020-05-23 menu can now handle no csv test case
2020-05-27 updated how csv files are created
    [current-state.csv, desired-state.csv]
2020-05-30 consolidated shutdown and restart scripts into power.py
2020-05-30 fixed formatting on controller.py
    [controller.py]
2020-05-30 fixed executeable power.py
    ufw bug is present so I temporarly ufw from firstboot.sh
    [controller.py]
2020-06-04 closed #64 leds now have sleep when run and renamed power.py to shutdown-restart.py
2020-06-09 moving documenation around
    [arduino.brd, motor-board.brd, pi-controller.yml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]
2020-06-18 closed #68 controler menu flow
2020-10-05 updated debounce in arduino.ino
2020-10-25 added parts
    [arduino.brd, motor-board.brd, mount5_part1.stl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]
